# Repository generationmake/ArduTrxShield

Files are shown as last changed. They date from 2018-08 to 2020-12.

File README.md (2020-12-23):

# ArduTrxShield
ArduTrx - Open Source Hamradio Transceiver for Arduino compatible to Arduino Uno

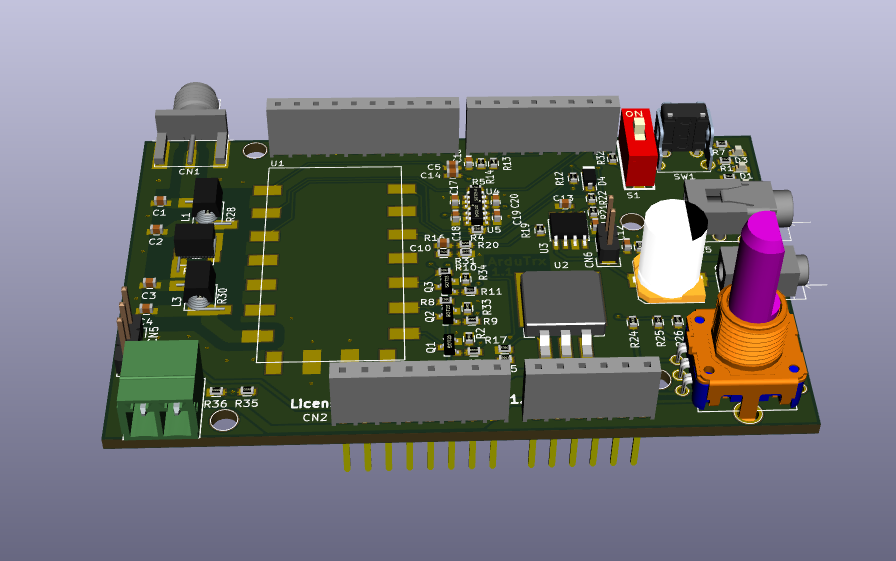
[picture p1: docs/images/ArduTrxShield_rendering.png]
ArduTrxShield rendering


## PCB

### Top

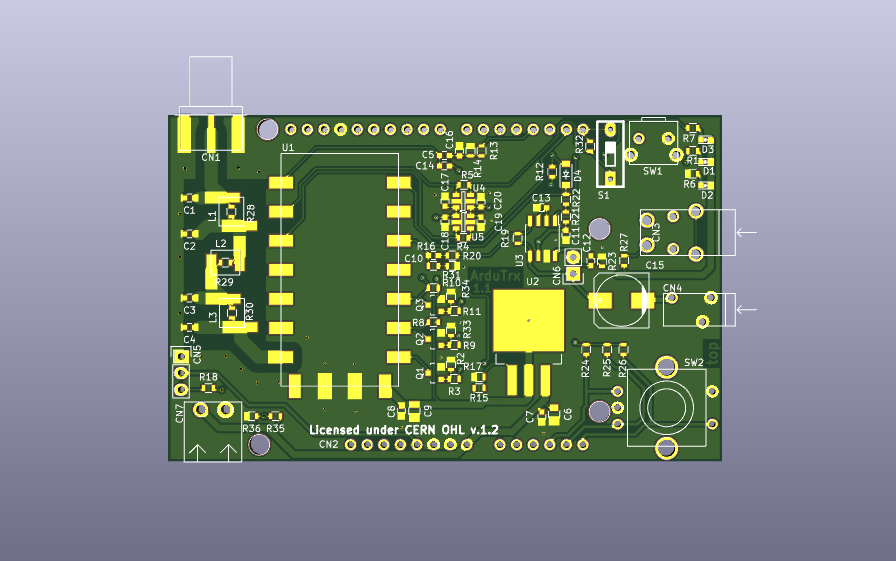
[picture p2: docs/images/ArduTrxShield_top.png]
ArduTrxShield PCB top


### Bottom

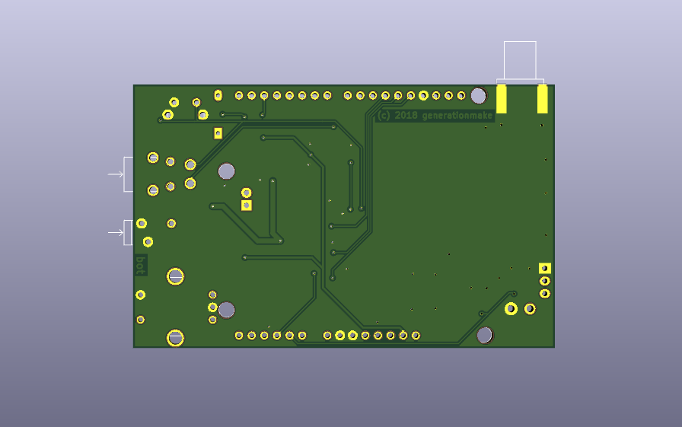
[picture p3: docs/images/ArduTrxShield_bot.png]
ArduTrxShield PCB bot


## License

This hardware is licensed under the CERN OHL v. 1.2

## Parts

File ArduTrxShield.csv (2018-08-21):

Id | Designator | Package | Quantity | Designation | Supplier and ref
1 | CN2 | ARDUINO | 1 | ARDUINO
2 | CN1 | WR-SMA-PCB | 1 | 60312202114509
3 | L1,L2,L3 | WE-CAIR_4248 | 3 | 744912156
4 | U1 | DRA818 | 1 | DRA818
5 | U2 | TO-263-3Lead | 1 | LT1085
6 | U3 | SOIC-8_3.9x4.9mm_Pitch1.27mm | 1 | LM4871
7 | Q1,Q2,Q3 | SOT-23 | 3 | 2N7002
8 | SW2 | ALPS_EC11E | 1 | ALPS_EC11E
9 | CN4 | 1501_03 | 1 | CON_KLINKE3
10 | SW1 | WE_4312x6xxx7x6 | 1 | TAST_HOR
11 | CN5 | Pin_Header_Straight_1x03 | 1 | CONN_01X03
12 | CN6 | Pin_Header_Straight_1x02 | 1 | CONN_01X02
13 | C15 | c_elec_8x10.5 | 1 | 470u
14 | C1,C4 | C_0603 | 2 | 30p
15 | C2,C3 | C_0603 | 2 | 47p
16 | C5,C7,C8,C10,C11,C12,C14,C16,C17,C18,C19,C20 | C_0603 | 12 | 100n
17 | C6,C9 | C_0805 | 2 | 10u
18 | C13 | C_0603 | 1 | 1u
19 | D1 | LED_0603 | 1 | Led_red
20 | D2 | LED_0603 | 1 | Led_yellow
21 | D3 | LED_0603 | 1 | Led_green
22 | D4 | SOD-123 | 1 | BAT46ZFILM
23 | R1,R6,R7,R8,R10,R14,R16,R24,R25,R26,R31 | R_0603 | 11 | 1k
24 | R3,R9,R11,R18,R22 | R_0603 | 5 | 100
25 | R4,R5,R28,R29,R30,R32 | R_0603 | 6 | DNI
26 | R12,R13,R21,R27,R2,R33,R34 | R_0603 | 7 | 4k7
27 | R15 | R_0603 | 1 | 121
28 | R17 | R_0603 | 1 | 300
29 | R19,R20,R36 | R_0603 | 3 | 20k
30 | R23 | R_0603 | 1 | 2k
31 | S1 | dip_1-300 | 1 | SW_DIP_x1
32 | U4,U5 | SOT-23-6 | 2 | SN74LVC1T45
33 | CN3 | 1503_07 | 1 | CON_KLINKE3
34 | R35 | R_0603 | 1 | 100k
35 | CN7 | WR-TBL_691322310002 | 1 | 691322310002

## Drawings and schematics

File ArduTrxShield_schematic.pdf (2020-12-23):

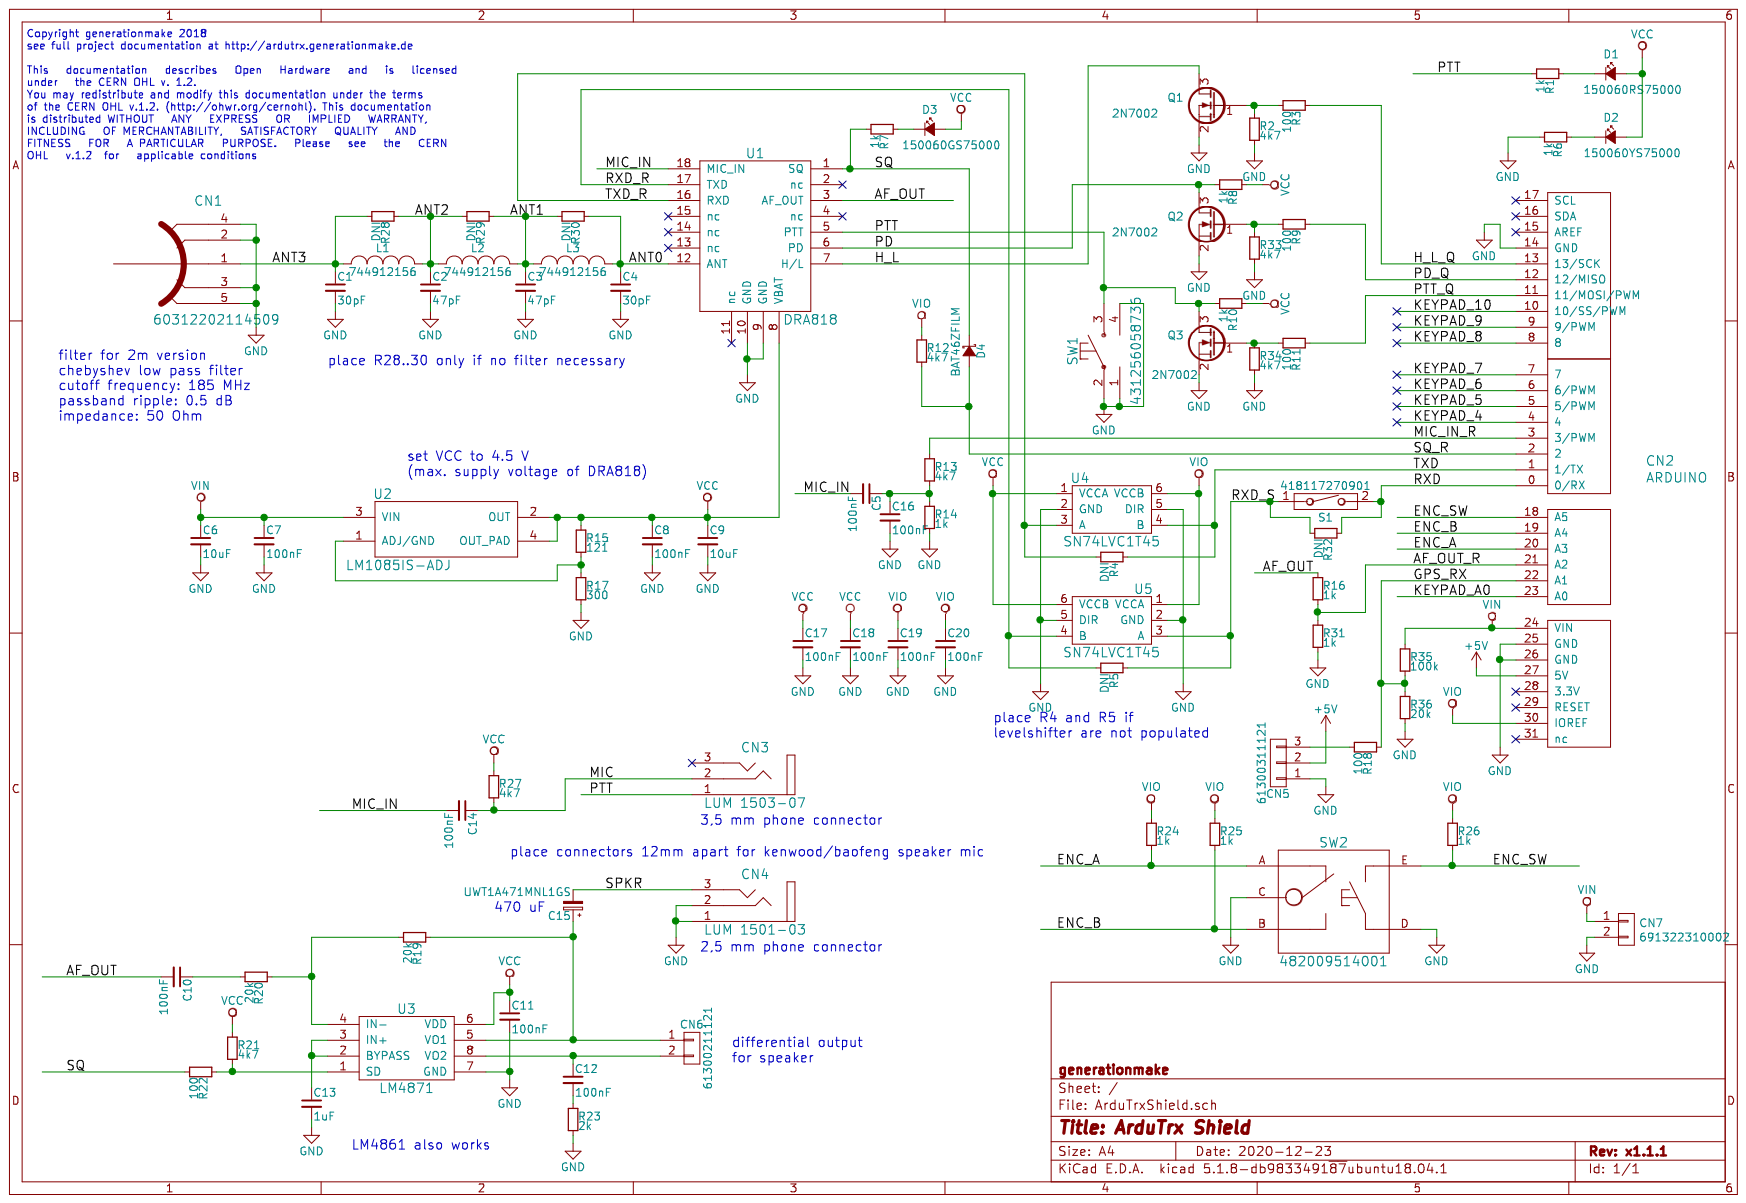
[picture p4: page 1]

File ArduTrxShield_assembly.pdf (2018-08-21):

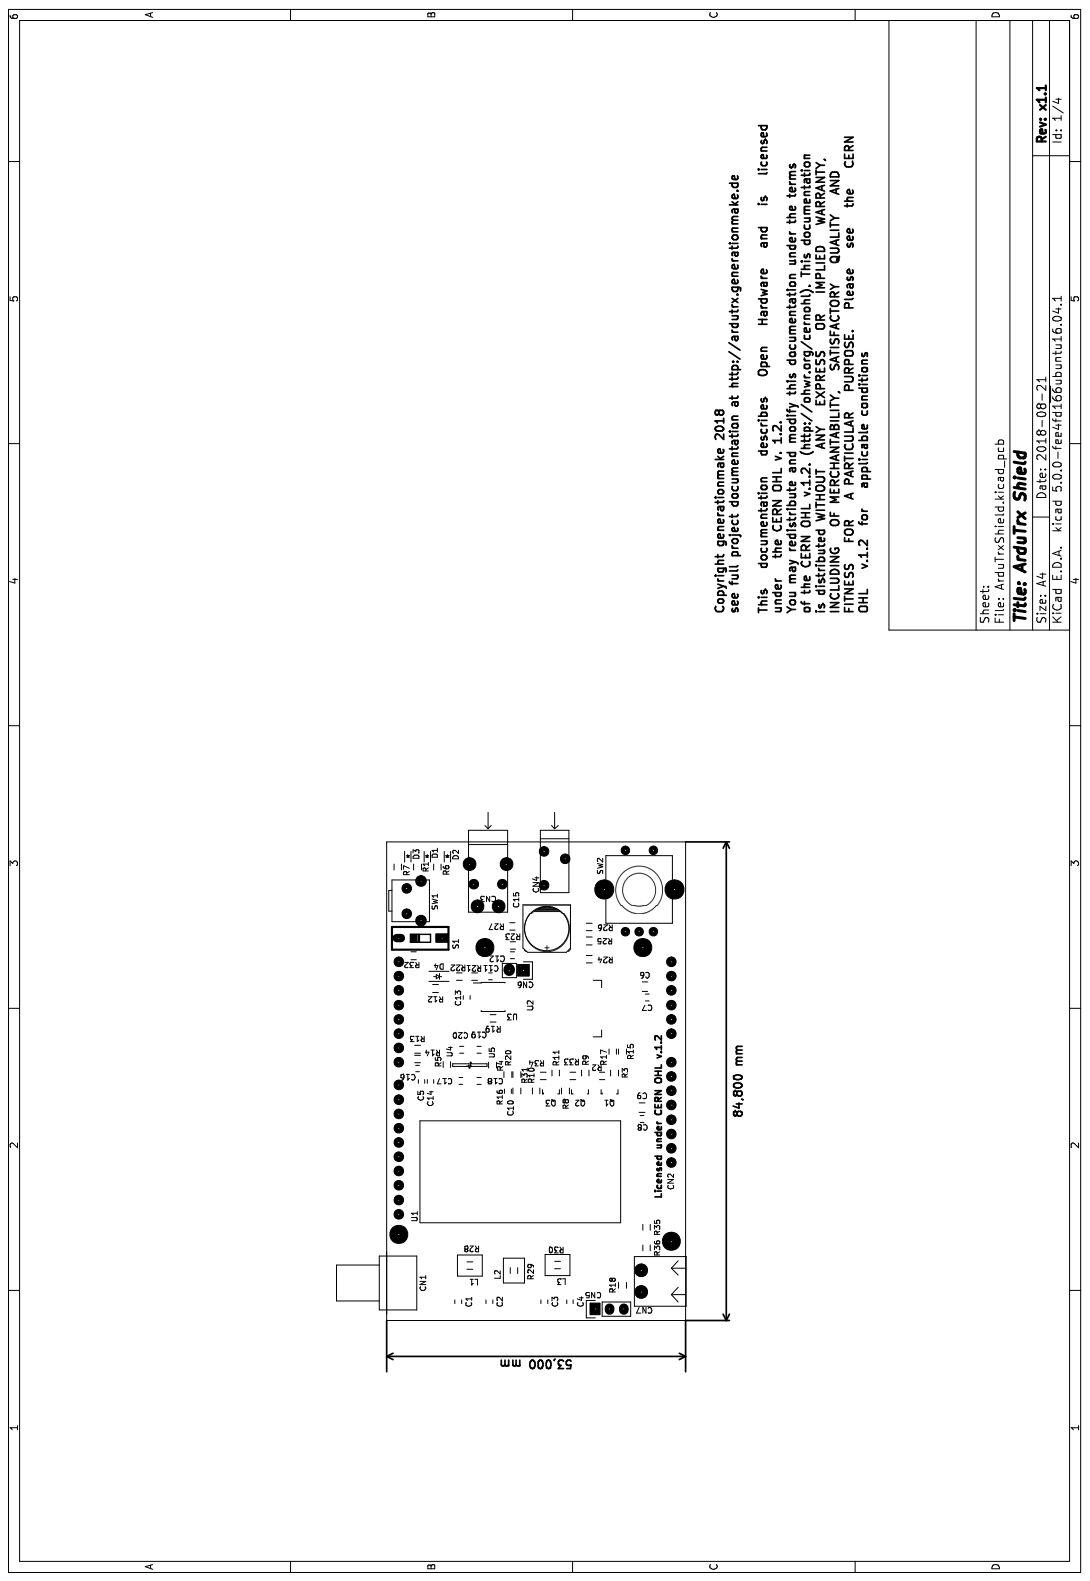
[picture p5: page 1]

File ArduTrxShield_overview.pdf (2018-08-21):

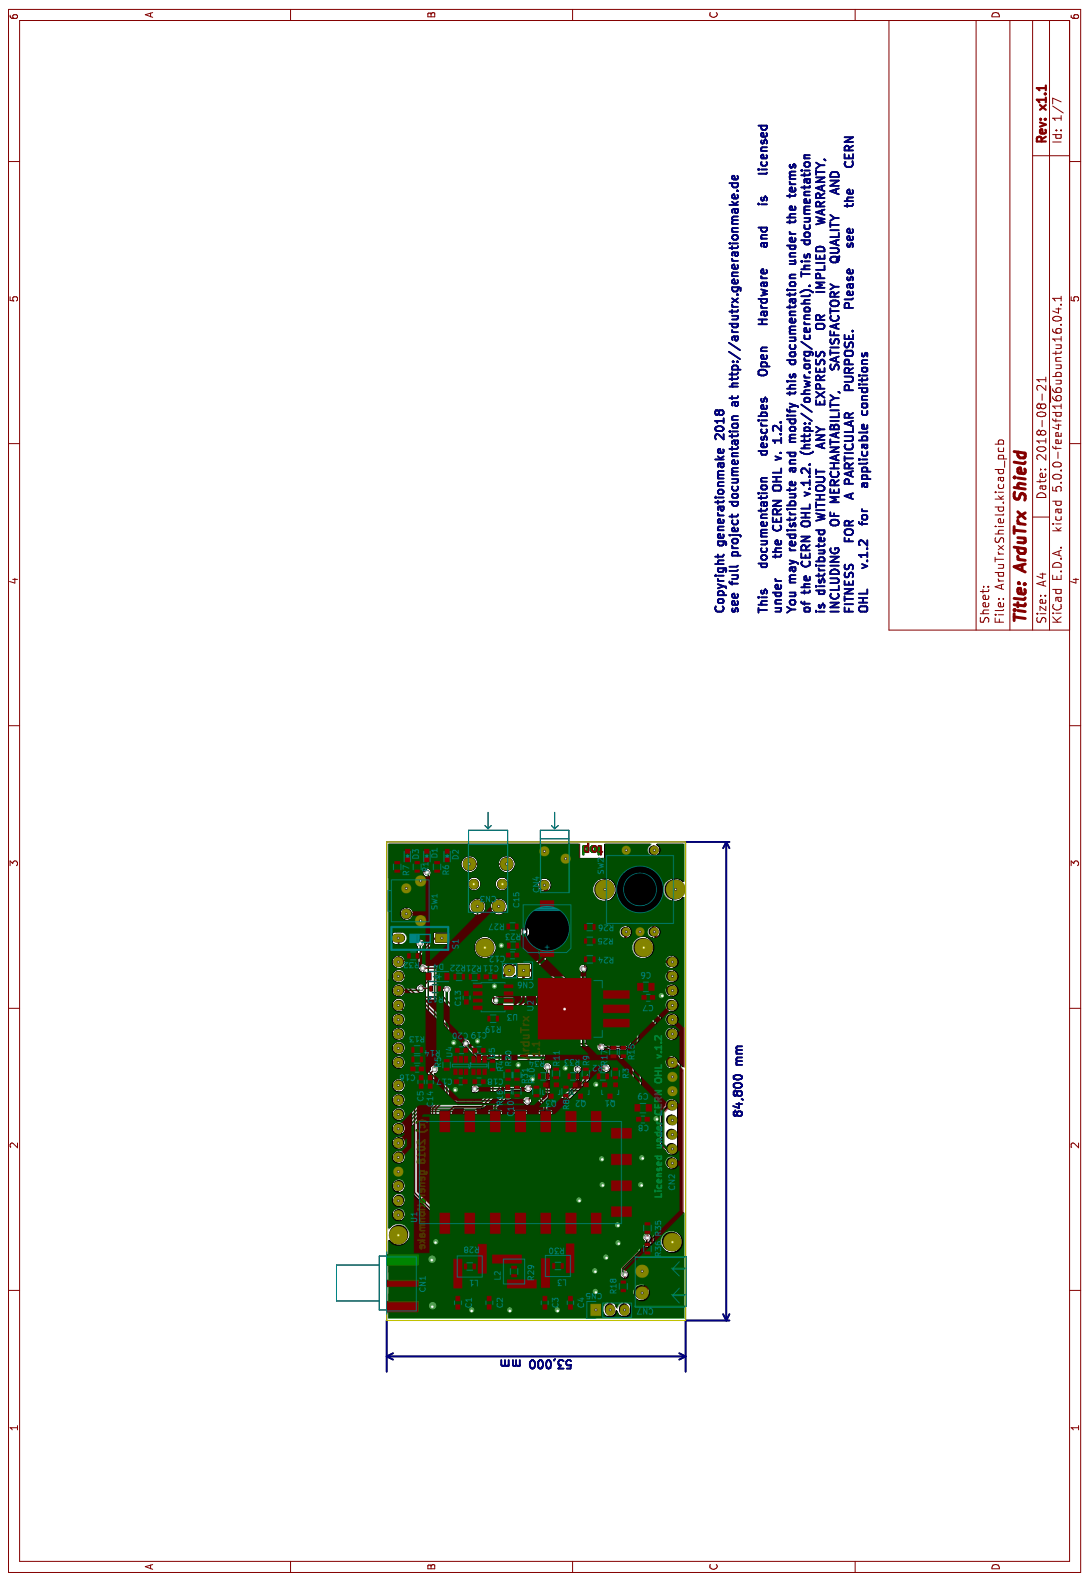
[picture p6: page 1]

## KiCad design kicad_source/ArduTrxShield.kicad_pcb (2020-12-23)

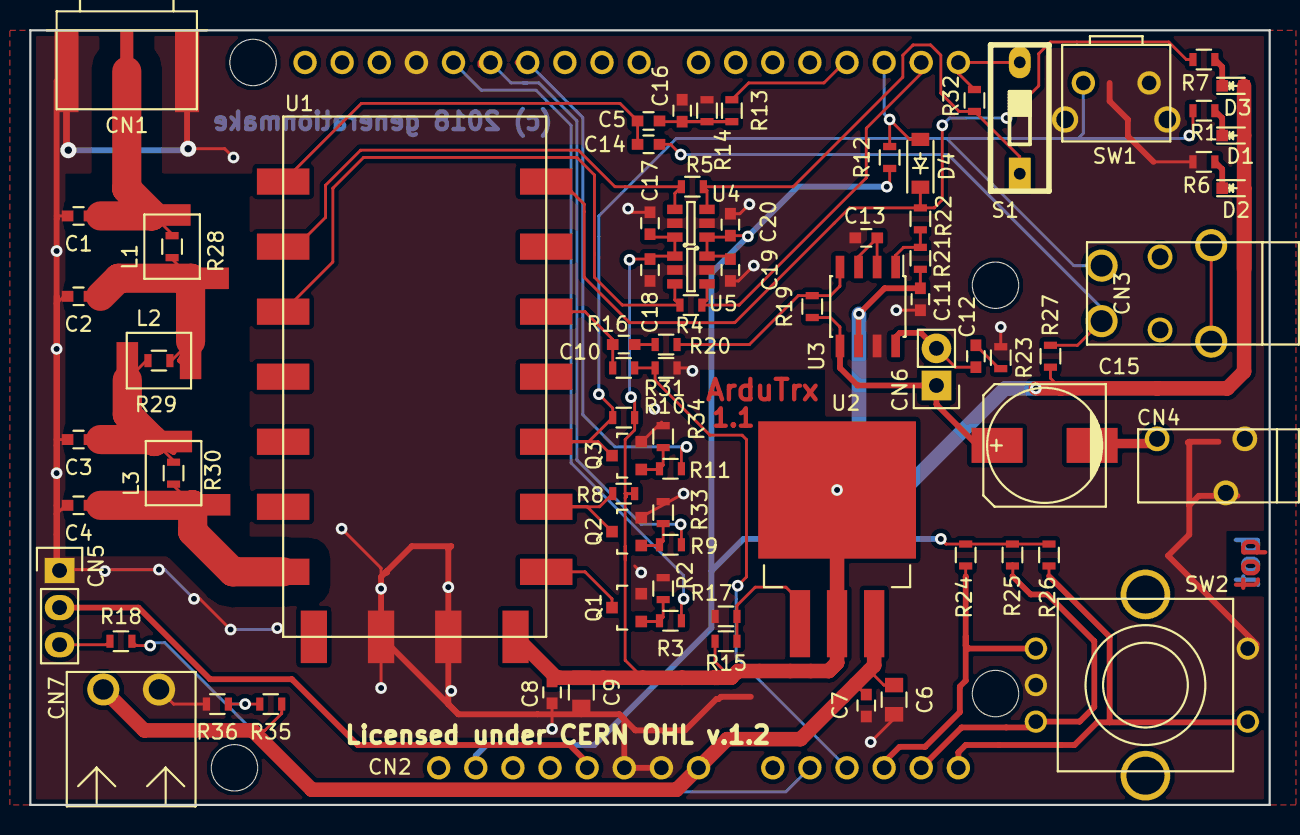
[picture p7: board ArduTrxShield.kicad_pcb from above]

Board: 2 copper layers, 84.8 x 53.0 mm, 81 parts (0 on the bottom side), 48 nets.

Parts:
C1, C4: 30pF; C_0603
C2, C3: 47pF; C_0603
C5, C7, C8, C10, C11, C12, C14, C16, C17, C18, C19, C20: 100nF; C_0603
C6, C9: 10uF; C_0805
C13: 1uF; C_0603
C15: UWT1A471MNL1GS; c_elec_8x10.5
CN1: 60312202114509; WR-SMA-PCB
CN2: ARDUINO
CN3: LUM 1503-07; 1503_07
CN4: LUM 1501-03; 1501_03
CN5: 61300311121; Pin_Header_Straight_1x03
CN6: 61300211121; Pin_Header_Straight_1x02
CN7: 691322310002; WR-TBL_691322310002
D1: 150060RS75000; LED_0603
D2: 150060YS75000; LED_0603
D3: 150060GS75000; LED_0603
D4: BAT46ZFILM; SOD-123
L1, L2, L3: 744912156; WE-CAIR_4248
Q1, Q2, Q3: 2N7002; SOT-23
R1, R6, R7, R8, R10, R14, R16, R24, R25, R26, R31: 1k; R_0603
R2, R12, R13, R21, R27, R33, R34: 4k7; R_0603
R3, R9, R11, R18, R22: 100; R_0603
R4, R5, R28, R29, R30, R32: DNI; R_0603
R15: 121; R_0603
R17: 300; R_0603
R19, R20, R36: 20k; R_0603
R23: 2k; R_0603
R35: 100k; R_0603
S1: 418117270901; dip_1-300
SW1: 431256058736; WE_4312x6xxx7x6
SW2: 482009514001; ALPS_EC11E
U1: DRA818
U2: LM1085IS-ADJ; TO-263-3Lead
U3: LM4871; SOIC-8_3.9x4.9mm_Pitch1.27mm
U4, U5: SN74LVC1T45; SOT-23-6

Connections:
+5V: CN2.27, CN5.2
/AF_OUT: C10.2, R16.1, U1.3
/AF_OUT_R: CN2.21, R16.2, R31.1
/ANT0: C4.1, L3.2, R30.1, U1.12
/ANT1: C3.1, L2.2, L3.1, R29.1, R30.2
/ANT2: C2.1, L1.2, L2.1, R28.1, R29.2
/ANT3: C1.1, CN1.1, L1.1, R28.2
/ENC_A: CN2.20, R24.2, SW2.A
/ENC_B: CN2.19, R25.2, SW2.B
/ENC_SW: CN2.18, R26.2, SW2.E
/GPS_RX: CN2.22, R18.1, R35.2, R36.1
/H_L: Q1.3, U1.7
/H_L_Q: CN2.13, R3.1
/MIC: C14.1, CN3.2, R27.2
/MIC_IN: C5.2, C14.2, U1.18
/MIC_IN_R: CN2.3, R13.1
/PD: Q2.3, R8.2, U1.6
/PD_Q: CN2.12, R9.1
/PTT: CN3.1, Q3.3, R1.2, R10.2, SW1.3, U1.5
/PTT_Q: CN2.11, R11.1
/RXD: CN2.0, R32.1, S1.2
/RXD_R: R5.2, U1.17, U5.4
/RXD_S: R5.1, R32.2, S1.1, U5.3
/SPKR: C15.2, CN4.3
/SQ: D4.1, R7.2, R22.2, U1.1
/SQ_R: CN2.2, D4.2, R12.2
/TXD: CN2.1, R4.1, U4.4
/TXD_R: R4.2, U1.16, U4.3
GND: C1.2, C2.2, C3.2, C4.2, C6.2, C7.2, C8.2, C9.2, C11.2, C13.2, C16.2, C17.2, C18.2, C19.2, C20.2, CN1.2, CN1.3, CN1.4, CN1.5, CN2.14, CN2.25, CN2.26, CN4.1, CN4.2, CN5.1, CN7.2, Q1.2, Q2.2, Q3.2, R2.2, R6.2, R14.2, R17.2, R23.2, R31.2, R33.2, R34.2, R36.2, SW1.1, SW1.2, SW1.4, SW2.C, SW2.D, U1.9, U1.10, U3.7, U4.2, U4.5, U5.2, U5.5
unnamed: C10.1, R20.2
unnamed: C12.1, CN6.2, U3.8
unnamed: C12.2, R23.1
unnamed: C13.1, U3.2, U3.3
unnamed: C15.1, CN6.1, R19.1, U3.5
unnamed: C5.1, C16.1, R13.2, R14.1
unnamed: CN5.3, R18.2
unnamed: D1.1, R1.1
unnamed: D2.1, R6.1
unnamed: D3.1, R7.1
unnamed: Q1.1, R2.1, R3.2
unnamed: Q2.1, R9.2, R33.1
unnamed: Q3.1, R11.2, R34.1
unnamed: R15.2, R17.1, U2.1
unnamed: R19.2, R20.1, U3.4
unnamed: R21.2, R22.1, U3.1
VCC: C8.1, C9.1, C11.1, C17.1, C18.1, D1.2, D2.2, D3.2, R8.1, R10.1, R15.1, R21.1, R27.1, U1.8, U2.2, U2.4, U3.6, U4.1, U5.6
VIN: C6.1, C7.1, CN2.24, CN7.1, R35.1, U2.3
VIO: C19.1, C20.1, CN2.30, R12.1, R24.1, R25.1, R26.1, U4.6, U5.1

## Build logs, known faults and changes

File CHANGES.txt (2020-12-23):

ArduTrx - Open Source Hamradio Transceiver for Arduino
ArduTrxShield regular Version
bernhard@generationmake.de
see full project documentation at http://ardutrx.generationmake.de or https://github.com/generationmake/ArduTrxShield

changes

version 1.0 - 2018-07-20
* initial release

version 1.1 - 2018-08-21
* changed R12 and R21 to 4k7
* changed R17 to 300R
* changed R16 and R31 to 1k
* removed R2
* updated footprint of SW1 - bigger mounting holes
* corrected footprint of CN4
* changed footprint of CN3 to Lumberg 1503 07
* made pcb smaller and moved CN3 and CN4 closer to the edge for easier case integration
* added pulldown resistors R2, R33 and R34 at FETs to prevent malfunction if no arduino is connected
* possibility to measure VIN with R35 and R36 at A1 if no GPS receiver is connected
* added CN7 vor VIN to enable stand alone operation

version 1.1.1 - 2020-12-23
* updated some part numbers

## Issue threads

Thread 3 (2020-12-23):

alternative arduino pin usage

generationmake, 2020-12-23:
at the moment the SPI pins of the arduino connector are blocked and efficient control of a display is not possible.
give the opportunity to use different pins.

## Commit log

2018-07-16 initial release with ArduTrxShield CNC x1.0
    [ArduTrxShield.csv, ArduTrxShield.kicad_pcb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]
2018-07-16 update to version 1.1, changed C15 generated all data
    [ArduTrxShield.kicad_pcb, ArduTrxShield.sch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]
2018-07-16 new folder for standard version
    [ArduTrxShield.csv, ArduTrxShield.kicad_pcb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]
2018-07-17 updated layout and schematic
    [ArduTrxShield.kicad_pcb, ArduTrxShield.sch]
2018-07-18 generated gerber output
    [ArduTrxShield-B.Cu.gbl, ArduTrxShield-B.Cu.gbr, ArduTrxShield-B.Mask.gbs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]
2018-07-20 generated and updated output data and pdfs
    [ArduTrxShield-B.Cu.gbl, ArduTrxShield-B.Mask.gbs, ArduTrxShield-Edge.Cuts.gm1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]
2018-07-20 corrected BOM
    [ArduTrxShield.csv]
2018-08-21 updated schematic and layout of ArduTrxShield to version 1.1, see CHANGES.txt for details
    [ArduTrxShield-B.Cu.gbl, ArduTrxShield-B.Mask.gbs, ArduTrxShield-Edge.Cuts.gm1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]
2018-08-27 fixed schematic symbol links to library
    [ArduTrxShield.sch]
2018-08-27 added DMR version. started with schematic and layout. needs to be checked
    [ArduTrxDMRShield.csv, ArduTrxDMRShield.kicad_pcb, ArduTrxDMRShield.sch]
2018-09-19 updated footprints with 3D-models
    [ArduTrxDMRShield.kicad_pcb]
2018-09-20 added 3d models
    [ArduTrxShield.kicad_pcb]
2018-09-23 updated some footprints with 3d models
    [ArduTrxShield.kicad_pcb]
2018-10-09 corrected schematic, updated layout
    [ArduTrxDMRShield.kicad_pcb, ArduTrxDMRShield.sch]
2018-11-27 updated schematic and layout, connected some nets to 3.3v output of DMR818
    [ArduTrxDMRShield.kicad_pcb, ArduTrxDMRShield.sch]
2018-11-27 generated production files, pdf and gerber
    [ArduTrxDMRShield-B.Cu.gbl, ArduTrxDMRShield-B.Mask.gbs, ArduTrxDMRShield-Edge.Cuts.gm1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]
2018-11-28 updated documentation, added description of circuit and BOM
2018-12-02 added arduino pin usage
2019-03-17 updated BOM added farnell order numbers and links
2019-04-27 added project DummyLoad
    [DummyLoad.kicad_pcb, DummyLoad.sch]
2019-04-27 added comments to schematic, added laber with license to pcb
    [DummyLoad.kicad_pcb, DummyLoad.sch]
2019-05-30 moved files to the correct folder
    [DummyLoad.kicad_pcb, DummyLoad.sch]
2019-05-30 added pdf files, licence files, gerber files. updated data for release, generated zip file
    [DummyLoad-B.Cu.gbl, DummyLoad-B.Mask.gbs, DummyLoad-B.Paste.gbp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]
2019-07-23 reworked schematic to have 50 ohms on input and output
    [DummyLoad.kicad_pcb, DummyLoad.sch]
2019-07-23 updated output files
    [DummyLoad-B.Cu.gbl, DummyLoad-B.Mask.gbs, DummyLoad-B.Paste.gbp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]
2020-11-29 removed unnecessary files
    [ArduTrxDMRShield-B.Cu.gbl, ArduTrxDMRShield-B.Mask.gbs, ArduTrxDMRShield-Edge.Cuts.gm1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]
2020-11-29 moved files to correct folder
    [ArduTrxShield-B.Cu.gbl, ArduTrxShield-B.Mask.gbs, ArduTrxShield-Edge.Cuts.gm1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]
2020-11-29 updated to latest kicad version
    [ArduTrxShield.kicad_pcb, ArduTrxShield.sch]
2020-11-29 updated bom, added part numbers
    [ArduTrxShield.kicad_pcb, ArduTrxShield.sch]
2020-12-23 updated part numbers
    [ArduTrxShield.kicad_pcb, ArduTrxShield.sch]
2020-12-23 updated schematic pdf
    [ArduTrxShield.sch]

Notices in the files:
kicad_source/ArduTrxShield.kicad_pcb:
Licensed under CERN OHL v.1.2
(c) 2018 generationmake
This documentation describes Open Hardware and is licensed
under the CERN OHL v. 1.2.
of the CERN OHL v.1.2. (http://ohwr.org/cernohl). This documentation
